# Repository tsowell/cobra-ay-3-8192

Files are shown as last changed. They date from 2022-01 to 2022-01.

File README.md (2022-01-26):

(Vezi [README-ro.md](README-ro.md) pentru o traducere greșită în română.)

# AY-3-8192 interface for Cobra

This is a simple AY-3-8192 interface for the expansion port of the Romanian
microcomputer Cobra.

The interface logic is based on the logic in the [Simple AY interface by
hw.speccy.cz][Simple AY interface], and the output mixing is
based on the Spectrum 128K.

The board has an input for the Cobra's beeper output and mixes it with the
AY-3-8192 output.

NOTE: This revision has not been tested yet.  It includes some simple fixes for
problems in the [previous revision][0da03c1], which is known to work.

[Simple AY interface]: https://hw.speccy.cz/ayinterface.html

[0da03c1]: https://github.com/tsowell/cobra-ay-3-8192/tree/0da03c1

## Images

Schematic

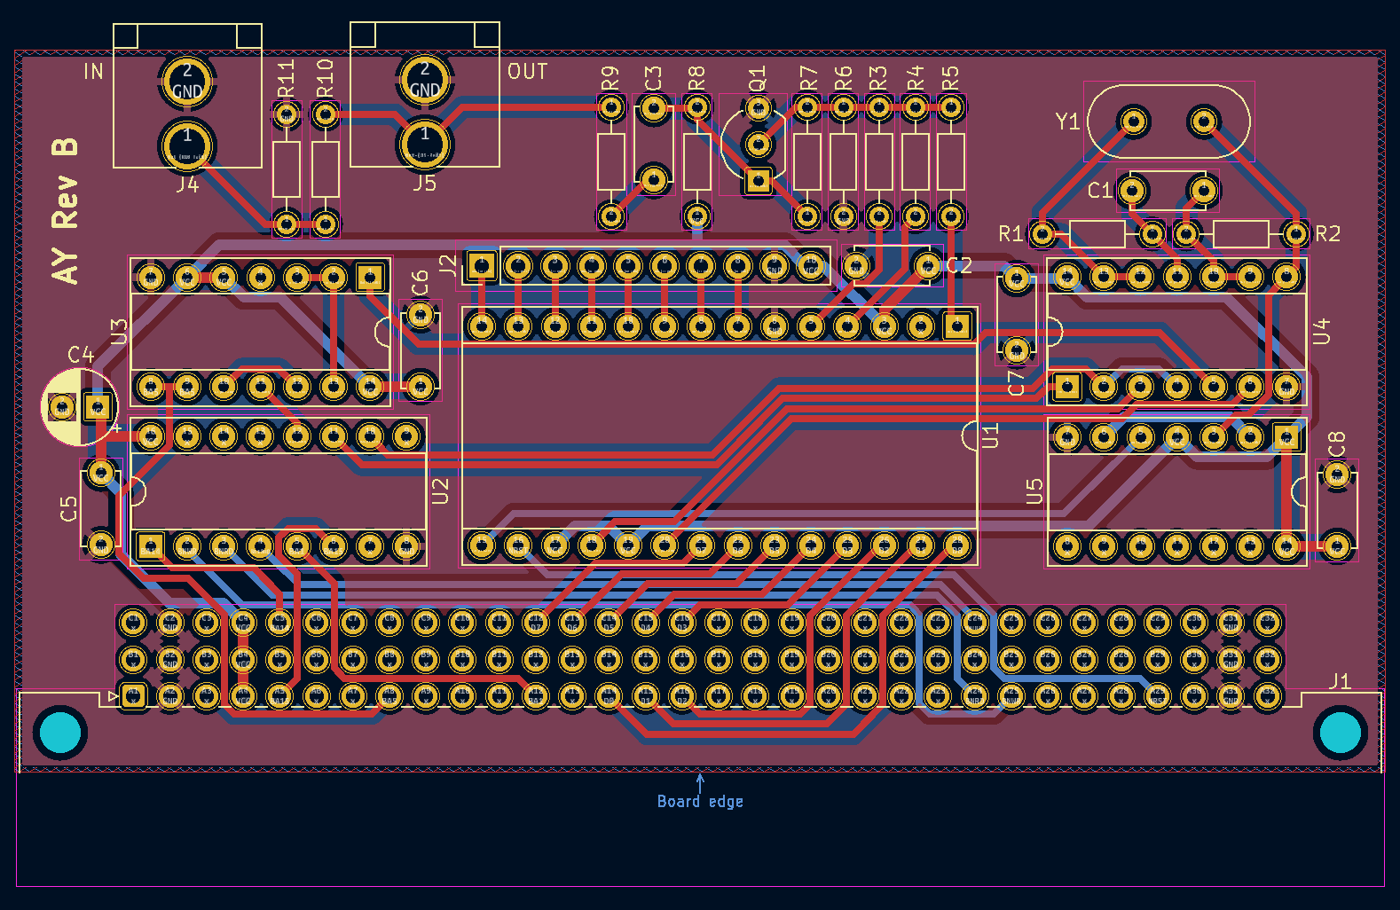
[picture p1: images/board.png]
PCB


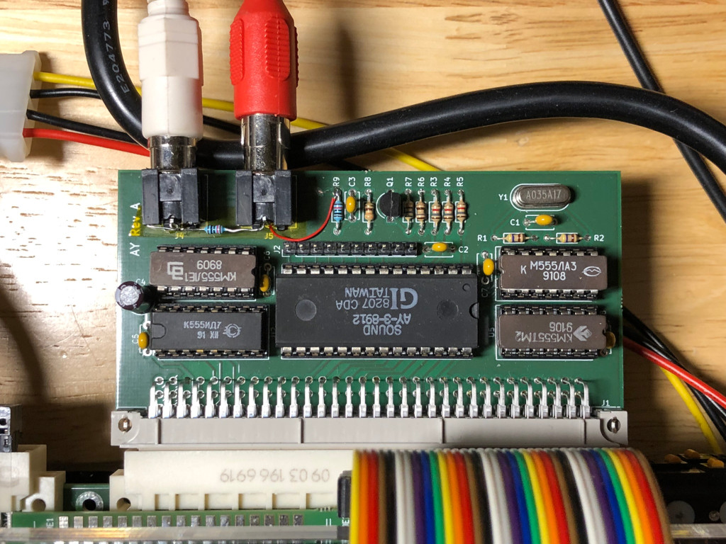
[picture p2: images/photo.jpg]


(shown with bodges)

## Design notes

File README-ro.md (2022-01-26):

# Interfața de AY-3-8192 pentru Cobra

Aceasta este o interfață simplă de AY-3-8192 pentru conectorul extensie al
microcalculatorului românesc Cobra.

Logicul de interfață se bazează pe logcul din [Simple AY interface de
hw.speccy.cz][Simple AY interface], și amestecarea ieșirii se bazează
Spectrum-ul 128K.

Interfața are o intrare pentru beeper-ul Cobra-ului și se amestecă cu ieșirea
AY-3-8192.

NOTĂ: Încă această revizuire nu a fost testat.  Include niște remedieri pentru
probleme în [revizuirea anterioară][0da03c1], care se știe că funcționa.

[Simple AY interface]: https://hw.speccy.cz/ayinterface.html

[0da03c1]: https://github.com/tsowell/cobra-ay-3-8192/tree/0da03c1

## Imagine

Schemă

PCB

Fotograf

(prezentat cu remedieri)

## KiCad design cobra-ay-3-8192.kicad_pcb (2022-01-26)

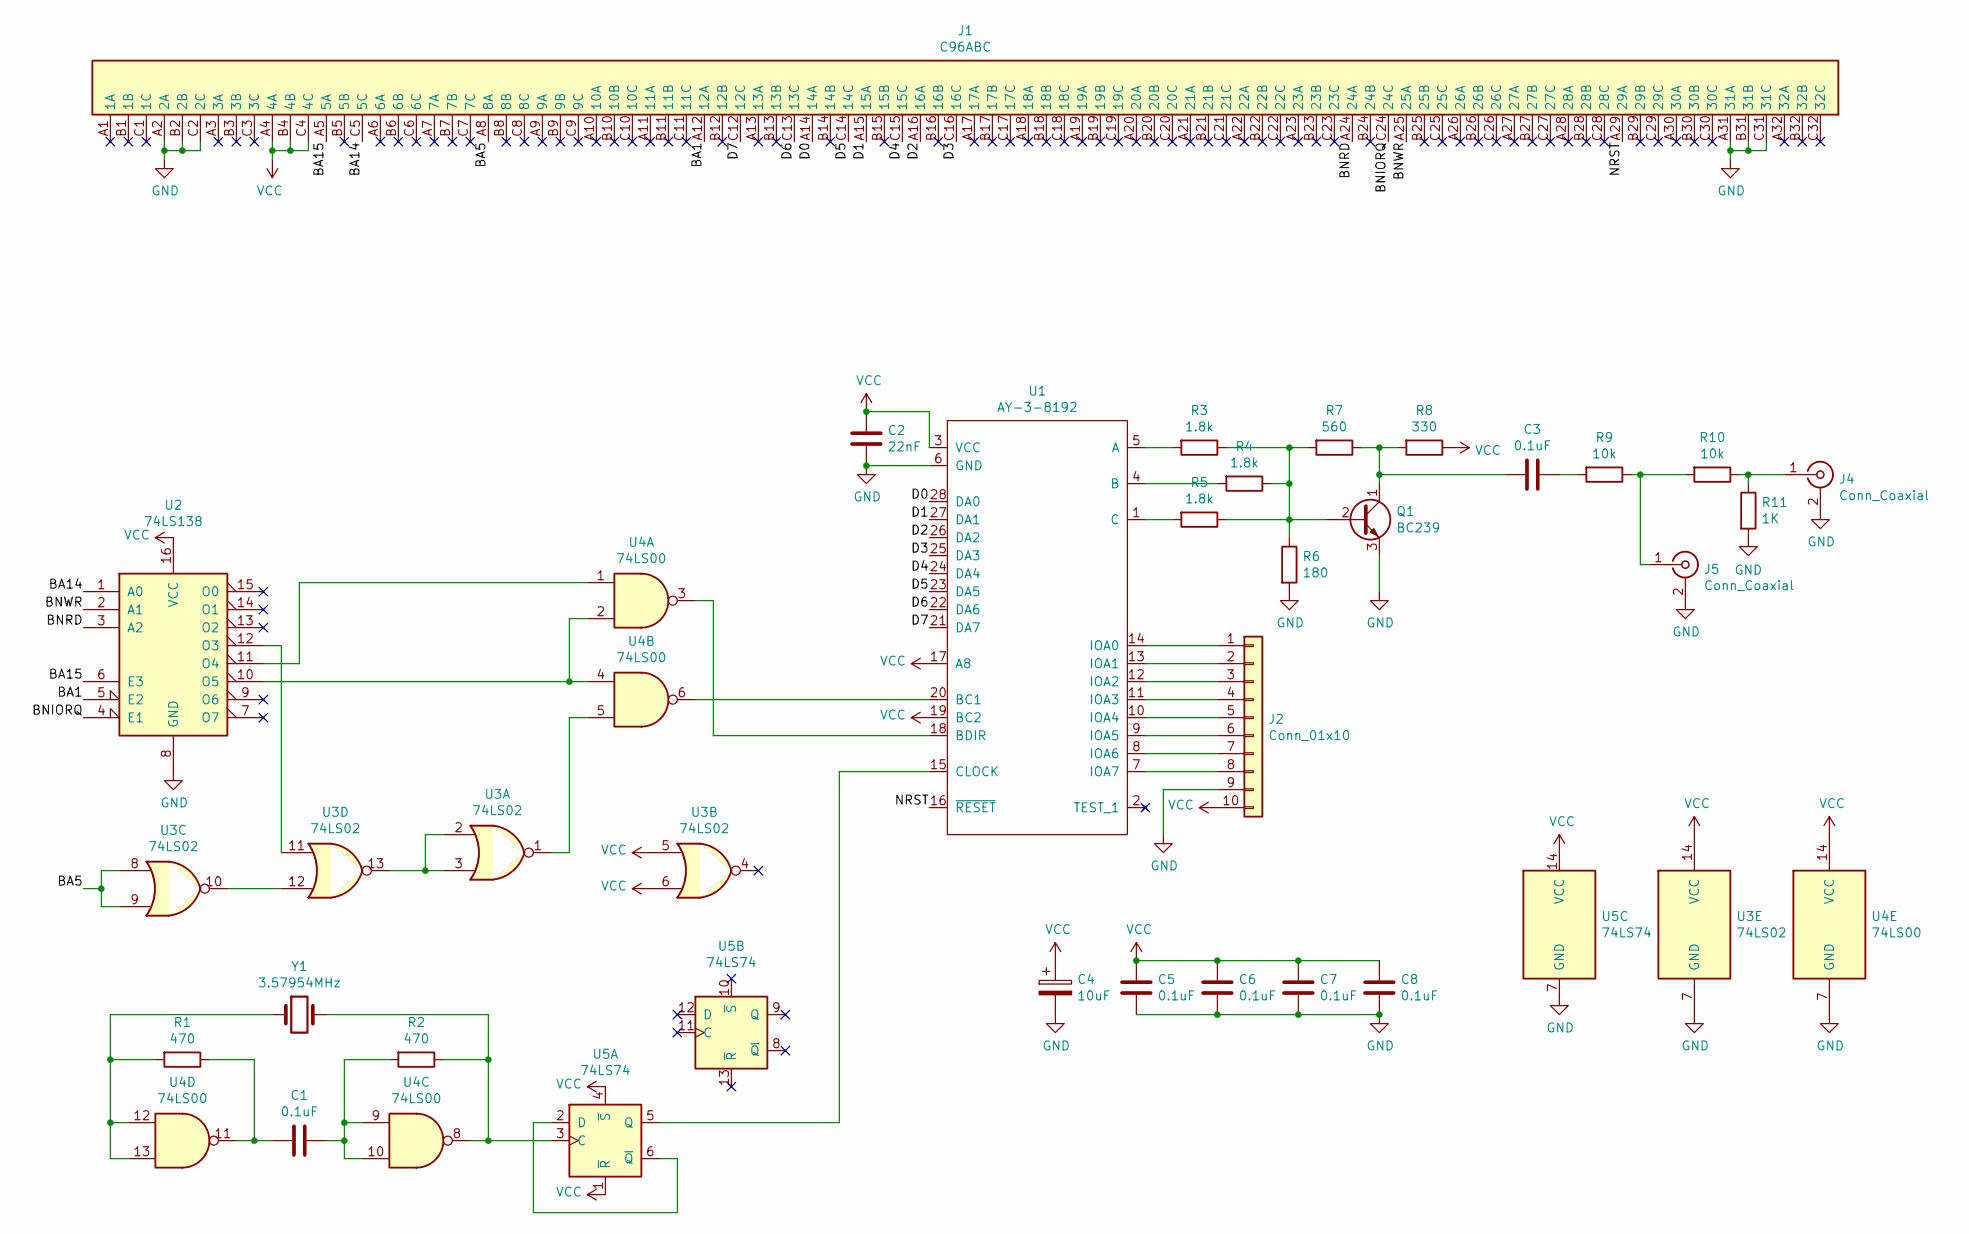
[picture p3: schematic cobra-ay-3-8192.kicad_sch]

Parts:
C1, C3, C5, C6, C7, C8: 0.1uF; C_Disc_D5.0mm_W2.5mm_P5.00mm
C2: 22nF; C_Disc_D5.0mm_W2.5mm_P5.00mm
C4: 10uF; CP_Radial_D5.0mm_P2.50mm
J1: C96ABC; DIN41612_C_3x32_Female_Horizontal_THT
J2: Conn_01x10; PinHeader_1x10_P2.54mm_Vertical
J4, J5: Conn_Coaxial; RCJ-04
Q1: BC239; TO-92_Inline_Wide
R1, R2: 470; R_Axial_DIN0204_L3.6mm_D1.6mm_P7.62mm_Horizontal
R3, R4, R5: 1.8k; R_Axial_DIN0204_L3.6mm_D1.6mm_P7.62mm_Horizontal
R6: 180; R_Axial_DIN0204_L3.6mm_D1.6mm_P7.62mm_Horizontal
R7: 560; R_Axial_DIN0204_L3.6mm_D1.6mm_P7.62mm_Horizontal
R8: 330; R_Axial_DIN0204_L3.6mm_D1.6mm_P7.62mm_Horizontal
R9, R10: 10k; R_Axial_DIN0204_L3.6mm_D1.6mm_P7.62mm_Horizontal
R11: 1K; R_Axial_DIN0204_L3.6mm_D1.6mm_P7.62mm_Horizontal
U1: AY-3-8192; DIP-28_W15.24mm_Socket
U2: 74LS138; DIP-16_W7.62mm_Socket
U3: 74LS02; DIP-14_W7.62mm_Socket
U4: 74LS00; DIP-14_W7.62mm_Socket
U5: 74LS74; DIP-14_W7.62mm_Socket
Y1: 3.57954MHz; Crystal_HC49-U_Vertical

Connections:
/BA1: J1.A12 (12A), U2.5 (E2)
/BA5: J1.A8 (8A), U3.8, U3.9
/BA14: J1.C5 (5C), U2.1 (A0)
/BA15: J1.A5 (5A), U2.6 (E3)
/BNIORQ: J1.C24 (24C), U2.4 (E1)
/BNRD: J1.A24 (24A), U2.3 (A2)
/BNWR: J1.A25 (25A), U2.2 (A1)
/D0: J1.A14 (14A), U1.28 (DA0)
/D1: J1.A15 (15A), U1.27 (DA1)
/D2: J1.A16 (16A), U1.26 (DA2)
/D3: J1.C16 (16C), U1.25 (DA3)
/D4: J1.C15 (15C), U1.24 (DA4)
/D5: J1.C14 (14C), U1.23 (DA5)
/D6: J1.C13 (13C), U1.22 (DA6)
/D7: J1.C12 (12C), U1.21 (DA7)
/NRST: J1.A29 (29A), U1.16 (~RESET)
GND: C2.2, C4.2, C5.2, C6.2, C7.2, C8.2, J1.A2 (2A), J1.A31 (31A), J1.B2 (2B), J1.B31 (31B), J1.C2 (2C), J1.C31 (31C), J2.9, J4.2 (Ext), J5.2 (Ext), Q1.3 (E), R6.2, R11.2, U1.6 (GND), U2.8 (GND), U3.7 (GND), U4.7 (GND), U5.7 (GND)
unnamed: C1.1, R2.2, U4.9, U4.10
unnamed: C1.2, R1.1, U4.11
unnamed: C3.1, R9.2
unnamed: C3.2, Q1.1 (C), R7.1, R8.2
unnamed: J2.1, U1.14 (IOA0)
unnamed: J2.2, U1.13 (IOA1)
unnamed: J2.3, U1.12 (IOA2)
unnamed: J2.4, U1.11 (IOA3)
unnamed: J2.5, U1.10 (IOA4)
unnamed: J2.6, U1.9 (IOA5)
unnamed: J2.7, U1.8 (IOA6)
unnamed: J2.8, U1.7 (IOA7)
unnamed: J5.1 (In), R9.1, R10.2
unnamed: Q1.2 (B), R3.1, R4.1, R5.1, R6.1, R7.2
unnamed: R1.2, U4.12, U4.13, Y1.1
unnamed: R2.1, U4.8, U5.3 (C), Y1.2
unnamed: R3.2, U1.5 (A)
unnamed: R4.2, U1.4 (B)
unnamed: R5.2, U1.1 (C)
unnamed: J4.1 (In), R10.1, R11.1
unnamed: U1.15 (CLOCK), U5.5 (Q)
unnamed: U1.18 (BDIR), U4.3
unnamed: U1.20 (BC1), U4.6
unnamed: U2.10 (O5), U4.2, U4.4
unnamed: U2.11 (O4), U4.1
unnamed: U2.12 (O3), U3.11
unnamed: U3.1, U4.5
unnamed: U3.10, U3.12
unnamed: U3.2, U3.3, U3.13
unnamed: U5.2 (D), U5.6 (~Q)
VCC: C2.1, C4.1, C5.1, C6.1, C7.1, C8.1, J1.A4 (4A), J1.B4 (4B), J1.C4 (4C), J2.10, R8.1, U1.3 (VCC), U1.17 (A8), U1.19 (BC2), U2.16 (VCC), U3.5, U3.6, U3.14 (VCC), U4.14 (VCC), U5.1 (~R), U5.4 (~S), U5.14 (VCC)

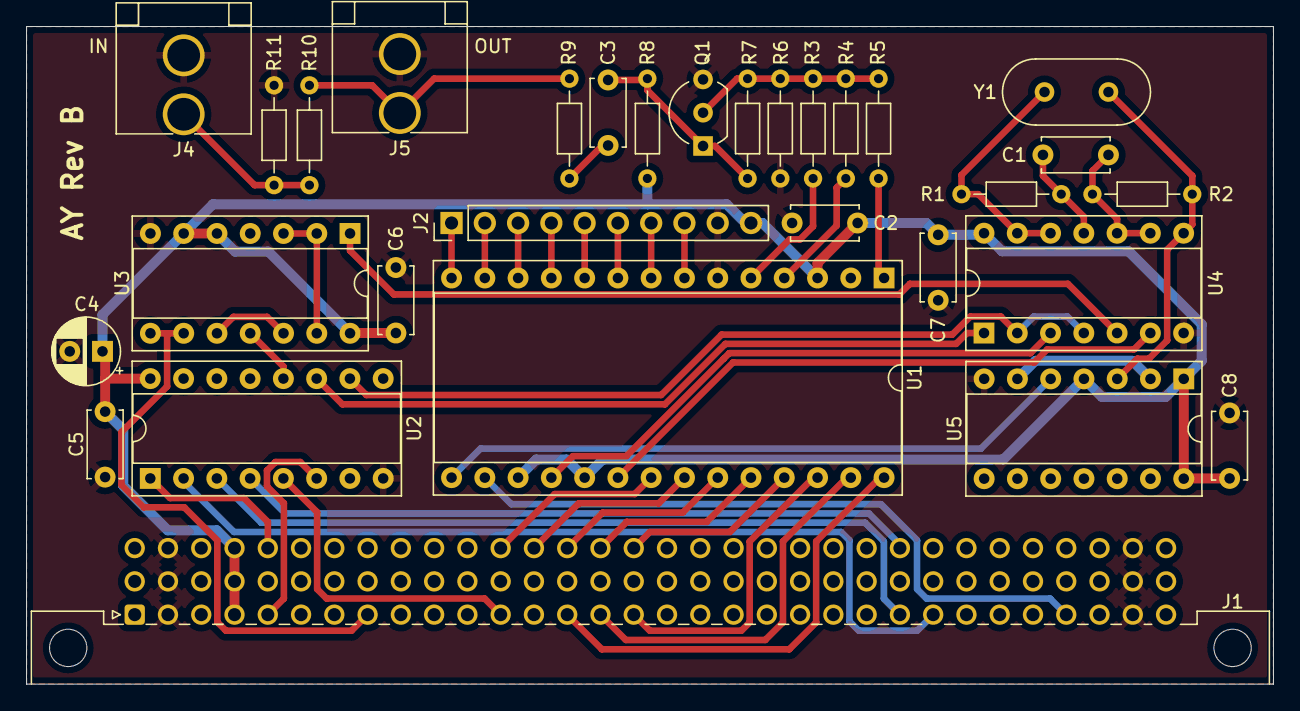
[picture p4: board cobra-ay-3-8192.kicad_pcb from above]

Board: 2 copper layers, 95.2 x 50.2 mm, 30 parts (0 on the bottom side), 48 nets.
